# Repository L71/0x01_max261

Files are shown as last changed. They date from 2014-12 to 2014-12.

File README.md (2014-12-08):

0x01_max261
===========

This Maxim Max261 based Eurorack filter module is making this filter IC useful
for audio processing in a standard 16HP Eurorack synth module. 
The IC is a dual filter and each filter is independently controlled using front
panel knobs and control voltage inputs. The filter mode selection buttons provide
these filter types in each filter section:
Low pass, band pass, high pass, notch (lowpass+highpass mixed).
The maximum frequency range is logarithmic 30Hz-16.6KHz with the current firmware.

There are separate knobs and CV inputs for the frequency and resonance of each filter.
The resulting control voltages are read by an Atmel ATmega328 microcontroller that
is programming the max261 filter IC. It also provides the clock signals to
the filter sections. 

The output of filter A is connected to the input of filter B if no cables are inserted.

The filter IC used is not built for use in musical instruments. It suffers from some
clock signal bleed (+- 4mV at 50x the filter cutoff frequency) and due to its switched
capacitor technology it behaves somewhat like a sampled system and has a Nyquist
frequency at 25x the filter cutoff frequency. The clock bleed will be audible in LP
mode with low cutoff values if the filter is the last unit in the signal chain.
Make sure to read the Maxim max261 data sheets if you plan to build one of these. 

The microcontroller source code is released under the GPL v3.0 license. 
The PCBs and front panel drawings are released under the Creative Commons CC BY-SA 4.0 license.

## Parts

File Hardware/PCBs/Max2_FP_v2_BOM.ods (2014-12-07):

Qty | Value | Device | Parts | Description
20 | 100k | R-EU_0207/2V | R1, R2, R3, R4, R6, R9, R11, R12, R13, R14, R15, R16, R19, R20, R21, R22, R23, R24, R25, R26
3 | 100n | C-EU025-025X050 | C7, C8, C9 | Ceramic capacitors
6 | 100n | C-EU050-025X075 | C5, C6, C11, C12, C13, C14 | DC elimination capacitors. Can be skipped if desired.
4 | 100p | C-EU025-025X050 | C1, C2, C3, C4 | Ceramics, 47-100pF OK.
4 | 10k | POT_USVERTICAL | R5_AF, R8_AQ, R17_BF, R18_BQ | ALPS 10K lin PCB mount potentiometer Mouser Pt No 688-RK09D1130C2P
2 | 1k | R-EU_0207/2V | R7, R10
8 | AUDIO-JACKERTHENVAR | AUDIO-JACKERTHENVAR | AU_A_IN, AU_A_OUT, AU_B_IN, AU_B_OUT, CV_AF_IN, CV_AQ_IN, CV_BF_IN, CV_BQ_IN | Switching Mono 3.5mm Audio Jack from Erthenvar.
1 | AUDIO | PINHD-1X10 | JP3 | Arduino board stacking connector (mounted on back side of PCB)
1 | CVs | PINHD-1X8 | JP2 | Arduino board stacking connector (mounted on back side of PCB)
1 | Power | PINHD-1X8 | JP1 | Arduino board stacking connector (mounted on back side of PCB)
6 | TL2285 | TL2285 | A_BP, A_HP, A_LP, B_BP, B_HP, B_LP | E-Switch TL2285 (PCB switch, latching) Mouser Pt.No. 612-TL2285EE300Q
1 | TS924N | TS924N | IC1 | R2R Opamp (Prototypes use TLV2374)
6 | cap for switch SW1 |  |  | Mouser part no 612-1RWHT, 612-1R-BK, 612-1R-RD
4 | knobs for potentiometers |  |  | The pots mentioned have 6mm D-shaped shafts. The panel is designed to have bigger knobs for the frequency settings.
1 | 0x01 Panel IO PCB
1 | 0x01 Front panel
8 | 12mm M3 spacer bolts |  |  | Total 8. Screw → front panel → spacer → PCB → spacer-> PCB → nut.
4 | 6mm M3 screws
4 | M3 nuts

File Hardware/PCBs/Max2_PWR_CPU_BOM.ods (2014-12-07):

Qty | Value | Device | Parts | Description
1 |  | AVR_SPI_PRG_6NS | ISP | AVR ISP 6 Pin header for MCU programming
1 |  | LED3MM | LED1 | LED for MCU life indicator
8 | 100K | R-EU_0207/2V | R1, R3, R7, R8, R11, R12, R15, R16
11 | 100nF | C-EU025-025X050 | C7, C8, C13, C21, C22, C23, C24, C27, C28, C33, C34 | Ceramic capacitors
1 | 10K | R-EU_0207/2V | R17
4 | 10nF | C-EU025-025X050 | C9, C10, C11, C12 | Ceramic capacitors
1 | 1K | R-EU_0207/2V | R2 | LED current limiting resistor. 4,7-10 K OK with very bright LEDs.
2 | 1N4004 | 1N4004 | D1, D2 | 1N4001 also OK.
1 | 20MHz | CRYSTALHC49S | Q1 | 20MHz crystal. Make sure its specs matches C2 and C3.
2 | 22pF | C-EU025-025X050 | C2, C3
4 | 22uF | CPOL-EUE2.5-7 | C1, C4, C5, C6 | Electrolytic capacitors
2 | 4,7uF | CPOL-EUE2.5-6 | C15, C16 | Electrolytic capacitors
1 | 7805 | 78XXS | IC3 | Voltage regulator +5V TO220
1 | 7905 | 79XXS | IC4 | Voltage regulator -5V TO220
1 | ATmega328P | MEGA8-P | IC2 | Atmel ATmega328P DIL28 microcontroller. Also works with (likely) 88s and 168s (tested).
1 | Eurorack power | PINHD-2X5 | JP1 | 2x5 2.54mm pin header for Eurorack power supply.
1 | MAX261 | MAX261 | IC1 | Maxim Max261 filter IC DIL24.
2 | MCP6002 | MCP602P | IC5, IC6 | Single Supply CMOS opamps
3 | pin headers |  |  | 2x8 pin, 1x10pin pin headers for board stacking (mounted on back side of PCB)

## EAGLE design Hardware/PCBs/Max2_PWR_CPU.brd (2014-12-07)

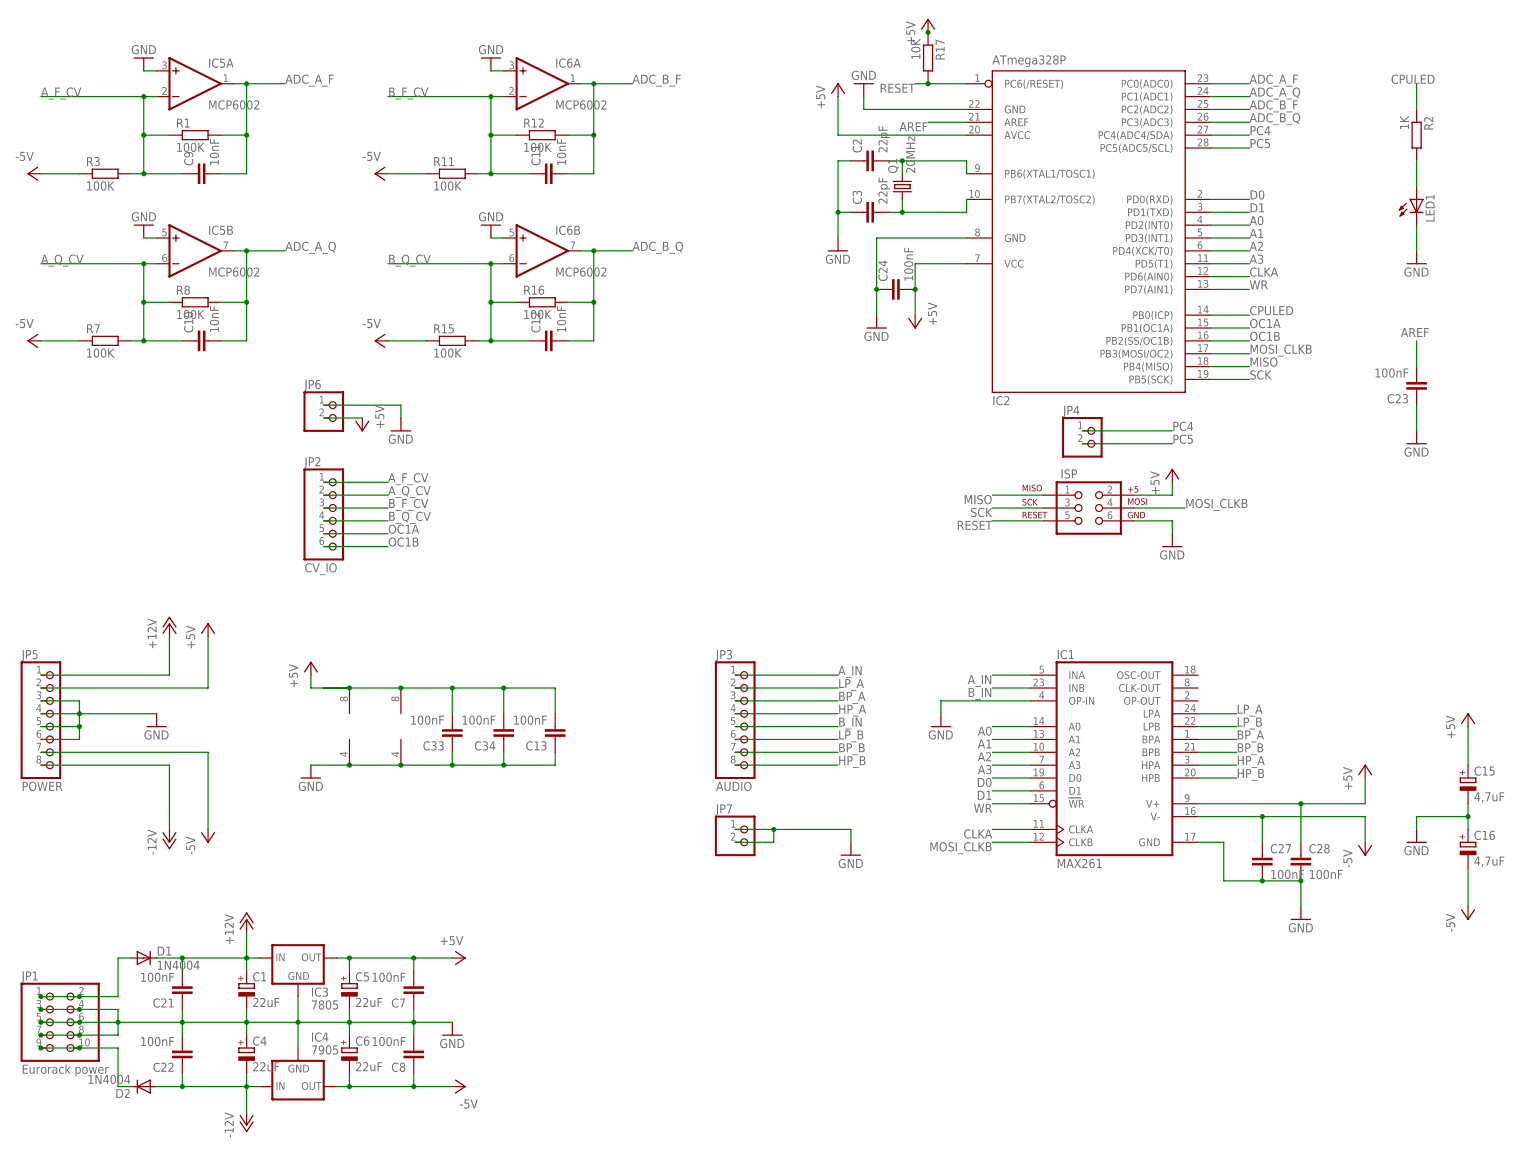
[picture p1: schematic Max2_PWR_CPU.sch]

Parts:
C1, C4, C5, C6: 22uF; E2,5-7
C2, C3: 22pF; C025-025X050
C7, C8, C13, C21, C22, C23, C24, C27, C28, C33, C34: 100nF; C025-025X050
C9, C10, C11, C12: 10nF; C025-025X050
C15, C16: 4,7uF; E2,5-6
D1, D2: 1N4004; DO41-10
IC1: MAX261; DIL24-3
IC2: ATmega328P; DIL28-3
IC3: 7805; 78XXS
IC4: 7905; 79XXS
IC5, IC6: MCP6002; DIL08
ISP: AVR_SPI_PRG_6NS; 2X3-NS
JP1: Eurorack power; 2X05
JP2: CV_IO; 1X06
JP3: AUDIO; 1X08
JP4, JP6, JP7: PINHD-1X2; 1X02
JP5: POWER; 1X08
LED1: LED3MM
Q1: 20MHz; HC49/S
R1, R3, R7, R8, R11, R12, R15, R16: 100K; 0207/2V
R2: 1K; 0207/2V
R17: 10K; 0207/2V

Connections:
+5V: C5.+, C7.2, C13.2, C15.+, C24.2, C28.1, C33.2, C34.2, IC1.9 (V+), IC2.7 (VCC), IC2.20 (AVCC), IC3.OUT, IC5.8 (V+), IC6.8 (V+), ISP.2, JP5.2, JP6.2, R17.1
+12V: C1.+, C21.2, D1.C, IC3.IN, JP5.1
-5V: C6.-, C8.1, C16.-, C27.1, IC1.16 (V-), IC4.OUT, JP5.7, R3.1, R7.1, R11.1, R15.1
-12V: C4.-, C22.1, D2.A, IC4.IN, JP5.8
A0: IC1.14 (A0), IC2.4 (PD2(INT0))
A1: IC1.13 (A1), IC2.5 (PD3(INT1))
A2: IC1.10 (A2), IC2.6 (PD4(XCK/T0))
A3: IC1.7 (A3), IC2.11 (PD5(T1))
ADC_A_F: C9.2, IC2.23 (PC0(ADC0)), IC5.1 (OUT), R1.2
ADC_A_Q: C10.2, IC2.24 (PC1(ADC1)), IC5.7 (OUT), R8.2
ADC_B_F: C11.2, IC2.25 (PC2(ADC2)), IC6.1 (OUT), R12.2
ADC_B_Q: C12.2, IC2.26 (PC3(ADC3)), IC6.7 (OUT), R16.2
AREF: C23.2, IC2.21 (AREF)
A_F_CV: C9.1, IC5.2 (-IN), JP2.1, R1.1, R3.2
A_IN: IC1.5 (INA), JP3.1
A_Q_CV: C10.1, IC5.6 (-IN), JP2.2, R7.2, R8.1
BP_A: IC1.1 (BPA), JP3.3
BP_B: IC1.21 (BPB), JP3.7
B_F_CV: C11.1, IC6.2 (-IN), JP2.3, R11.2, R12.1
B_IN: IC1.23 (INB), JP3.5
B_Q_CV: C12.1, IC6.6 (-IN), JP2.4, R15.2, R16.1
CLKA: IC1.11 (CLKA), IC2.12 (PD6(AIN0))
CPULED: IC2.14 (PB0(ICP)), R2.1
D0: IC1.19 (D0), IC2.2 (PD0(RXD))
D1: IC1.6 (D1), IC2.3 (PD1(TXD))
GND: C1.-, C2.1, C3.1, C4.+, C5.-, C6.+, C7.1, C8.2, C13.1, C15.-, C16.+, C21.1, C22.2, C23.1, C24.1, C27.2, C28.2, C33.1, C34.1, IC1.4 (OP-IN), IC1.17 (GND), IC2.8 (GND), IC2.22 (GND), IC3.GND, IC4.GND, IC5.3 (+IN), IC5.4 (V-), IC5.5 (+IN), IC6.3 (+IN), IC6.4 (V-), IC6.5 (+IN), ISP.6, JP1.3, JP1.4, JP1.5, JP1.6, JP1.7, JP1.8, JP5.3, JP5.4, JP5.5, JP5.6, JP6.1, JP7.1, JP7.2, LED1.K (C)
HP_A: IC1.3 (HPA), JP3.4
HP_B: IC1.20 (HPB), JP3.8
LP_A: IC1.24 (LPA), JP3.2
LP_B: IC1.22 (LPB), JP3.6
MISO: IC2.18 (PB4(MISO)), ISP.1
MOSI_CLKB: IC1.12 (CLKB), IC2.17 (PB3(MOSI/OC2)), ISP.4
unnamed: C2.2, IC2.9 (PB6(XTAL1/TOSC1)), Q1.2
unnamed: C3.2, IC2.10 (PB7(XTAL2/TOSC2)), Q1.1
unnamed: LED1.A, R2.2
unnamed: D1.A, JP1.1, JP1.2
unnamed: D2.C, JP1.9, JP1.10
OC1A: IC2.15 (PB1(OC1A)), JP2.5
OC1B: IC2.16 (PB2(SS/OC1B)), JP2.6
PC4: IC2.27 (PC4(ADC4/SDA)), JP4.1
PC5: IC2.28 (PC5(ADC5/SCL)), JP4.2
RESET: IC2.1 (PC6(/RESET)), ISP.5, R17.2
SCK: IC2.19 (PB5(SCK)), ISP.3
WR: IC1.15 (WR), IC2.13 (PD7(AIN1))

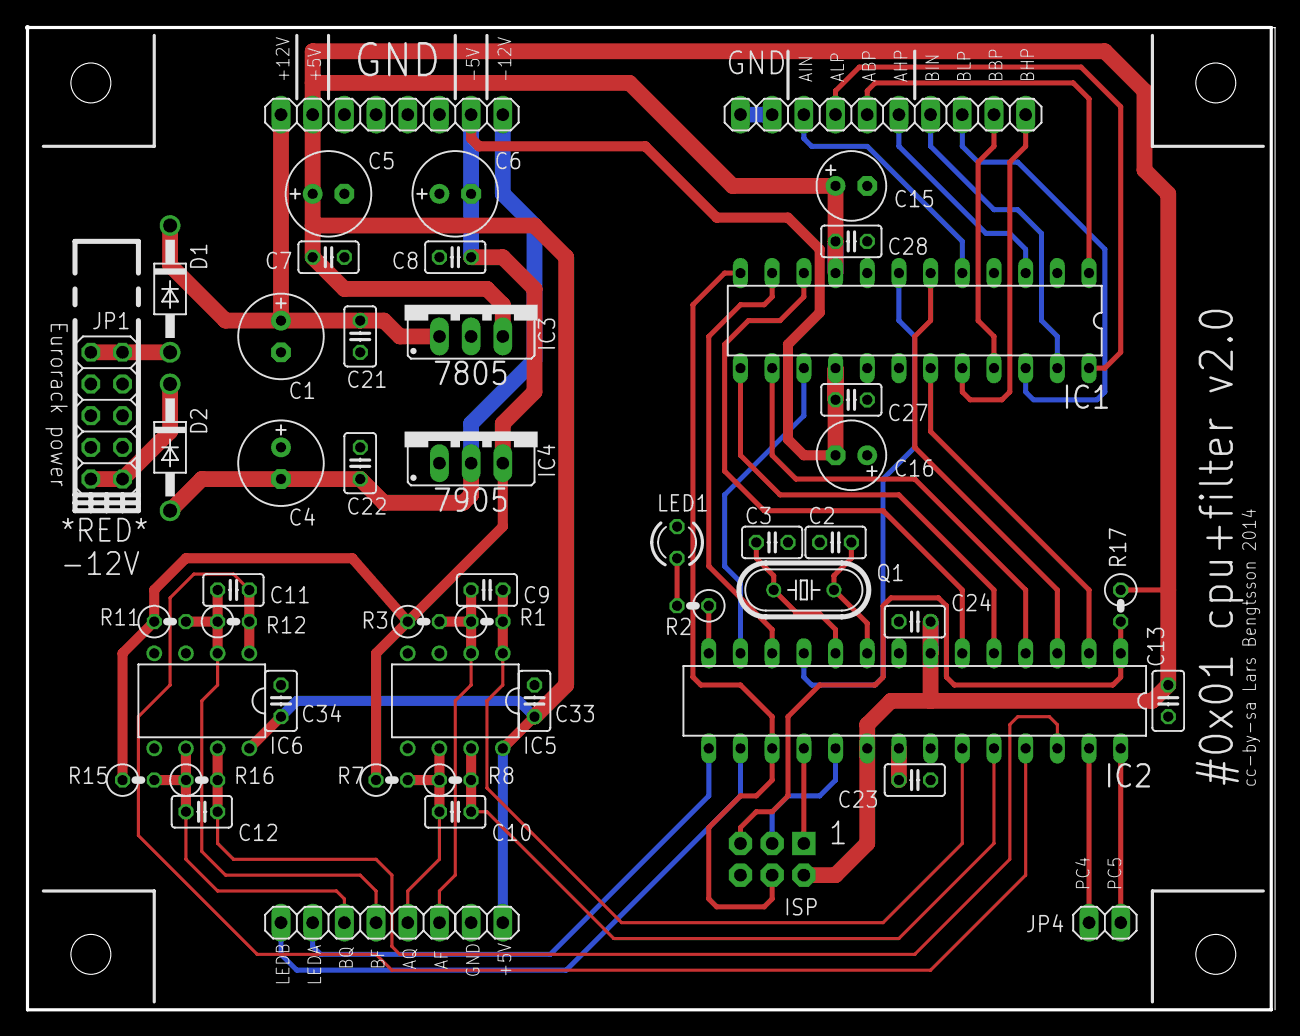
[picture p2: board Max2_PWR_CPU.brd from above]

Board: 2 copper layers, 99.7 x 78.7 mm, 51 parts (0 on the bottom side), 44 nets.

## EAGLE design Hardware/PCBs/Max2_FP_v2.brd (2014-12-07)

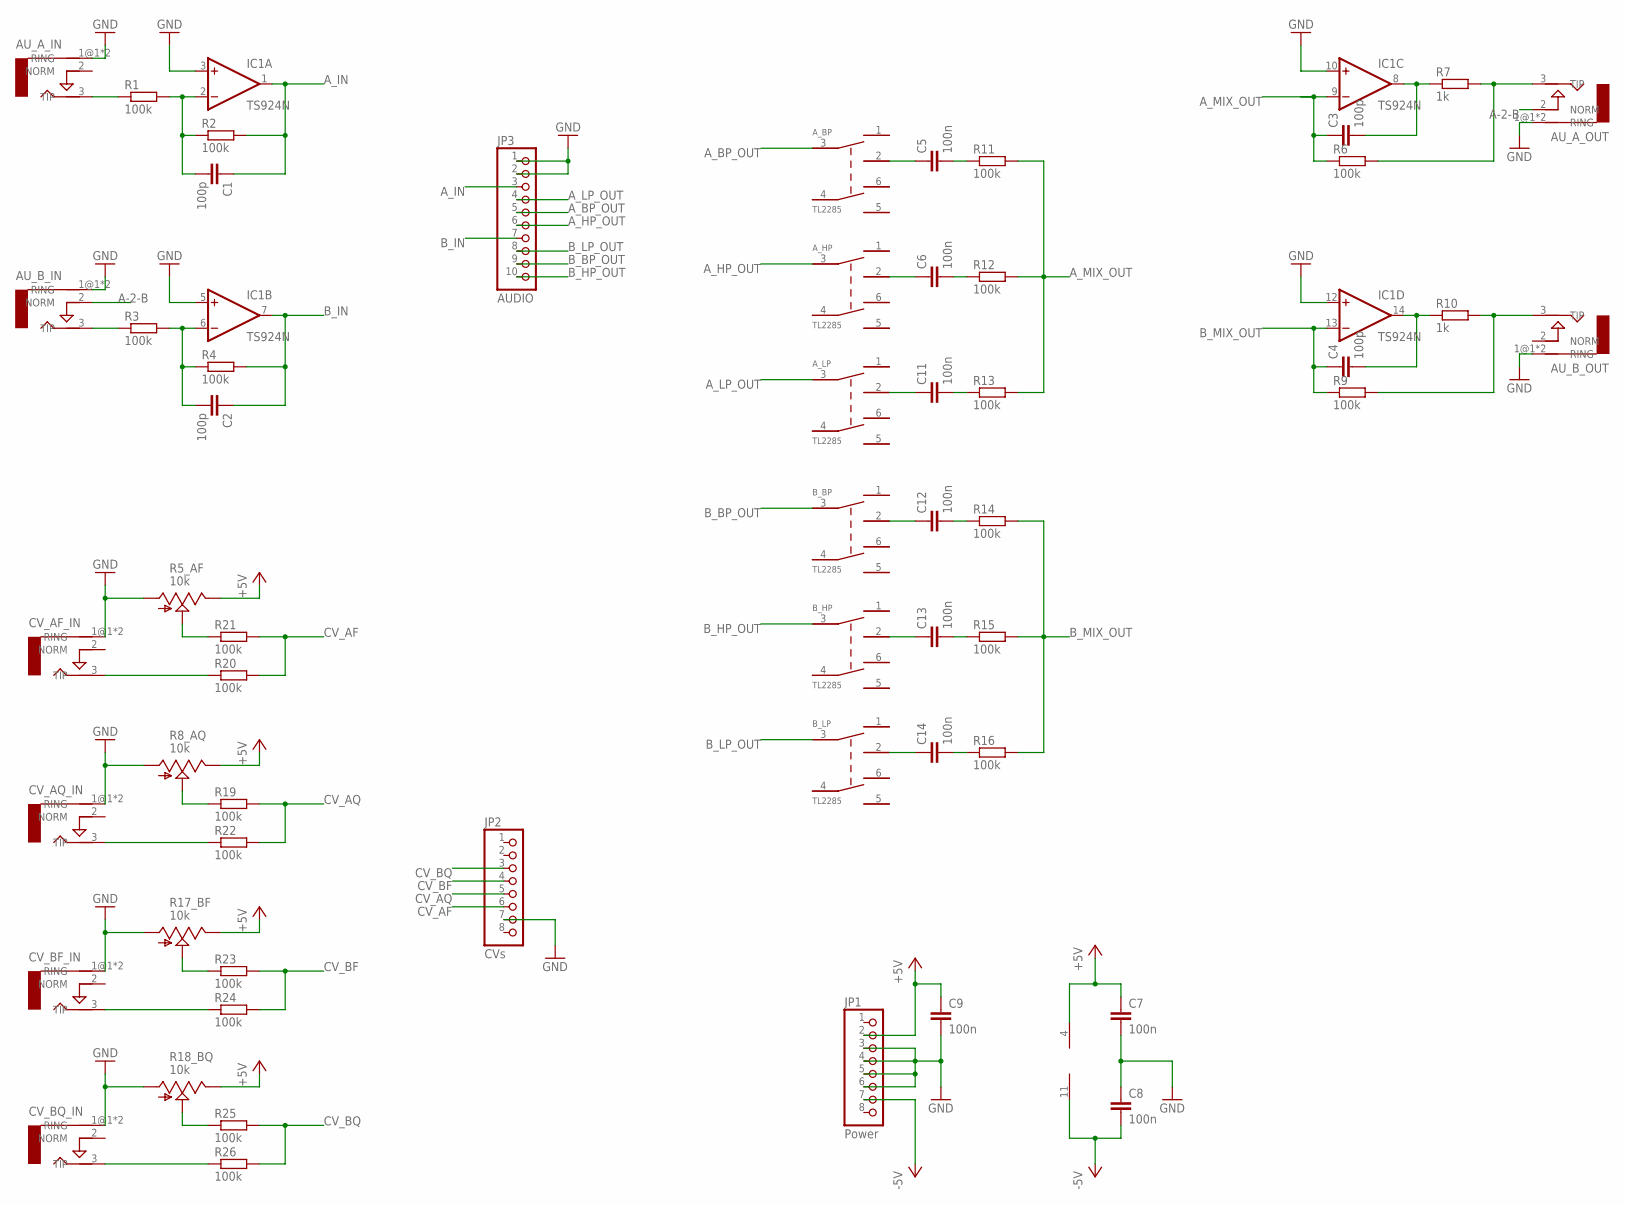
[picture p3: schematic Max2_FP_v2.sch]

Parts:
AU_A_IN: AUDIO-JACKERTHENVAR; ERTHENVAR-JACK
AU_A_OUT: AUDIO-JACKERTHENVAR; ERTHENVAR-JACK
AU_B_IN: AUDIO-JACKERTHENVAR; ERTHENVAR-JACK
AU_B_OUT: AUDIO-JACKERTHENVAR; ERTHENVAR-JACK
A_BP: TL2285; TL2285_PCB
A_HP: TL2285; TL2285_PCB
A_LP: TL2285; TL2285_PCB
B_BP: TL2285; TL2285_PCB
B_HP: TL2285; TL2285_PCB
B_LP: TL2285; TL2285_PCB
C1, C2, C3, C4: 100p; C025-025X050
C5, C6, C11, C12, C13, C14: 100n; C050-025X075
C7, C8, C9: 100n; C025-025X050
CV_AF_IN: AUDIO-JACKERTHENVAR; ERTHENVAR-JACK
CV_AQ_IN: AUDIO-JACKERTHENVAR; ERTHENVAR-JACK
CV_BF_IN: AUDIO-JACKERTHENVAR; ERTHENVAR-JACK
CV_BQ_IN: AUDIO-JACKERTHENVAR; ERTHENVAR-JACK
IC1: TS924N; DIL14
JP1: Power; 1X08
JP2: CVs; 1X08
JP3: AUDIO; 1X10
R1, R2, R3, R4, R6, R9, R11, R12, R13, R14, R15, R16, R19, R20, R21, R22, R23, R24, R25, R26: 100k; 0207/2V
R5_AF, R8_AQ, R17_BF, R18_BQ: 10k; ALPS_POT_VERTICAL
R7, R10: 1k; 0207/2V

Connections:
+5V: C7.1, C9.1, IC1.4 (V+), JP1.2, R5_AF.P$1 (E), R8_AQ.P$1 (E), R17_BF.P$1 (E), R18_BQ.P$1 (E)
-5V: C8.2, IC1.11 (V-), JP1.7
A-2-B: AU_A_OUT.2 (NORM), AU_B_IN.2 (NORM)
A_BP_OUT: A_BP.3, JP3.5
A_HP_OUT: A_HP.3, JP3.6
A_IN: C1.1, IC1.1 (OUT), JP3.3, R2.2
A_LP_OUT: A_LP.3, JP3.4
A_MIX_OUT: C3.1, IC1.9 (-IN), R6.1, R11.2, R12.2, R13.2
B_BP_OUT: B_BP.3, JP3.9
B_HP_OUT: B_HP.3, JP3.10
B_IN: C2.1, IC1.7 (OUT), JP3.7, R4.2
B_LP_OUT: B_LP.3, JP3.8
B_MIX_OUT: C4.1, IC1.13 (-IN), R9.1, R14.2, R15.2, R16.2
CV_AF: JP2.6, R20.2, R21.2
CV_AQ: JP2.5, R19.2, R22.2
CV_BF: JP2.4, R23.2, R24.2
CV_BQ: JP2.3, R25.2, R26.2
GND: AU_A_IN.1@1 (RING), AU_A_IN.1@2 (RING), AU_A_OUT.1@1 (RING), AU_A_OUT.1@2 (RING), AU_B_IN.1@1 (RING), AU_B_IN.1@2 (RING), AU_B_OUT.1@1 (RING), AU_B_OUT.1@2 (RING), C7.2, C8.1, C9.2, CV_AF_IN.1@1 (RING), CV_AF_IN.1@2 (RING), CV_AQ_IN.1@1 (RING), CV_AQ_IN.1@2 (RING), CV_BF_IN.1@1 (RING), CV_BF_IN.1@2 (RING), CV_BQ_IN.1@1 (RING), CV_BQ_IN.1@2 (RING), IC1.3 (+IN), IC1.5 (+IN), IC1.10 (+IN), IC1.12 (+IN), JP1.3, JP1.4, JP1.5, JP1.6, JP2.7, JP3.1, JP3.2, R5_AF.P$3 (A), R8_AQ.P$3 (A), R17_BF.P$3 (A), R18_BQ.P$3 (A)
unnamed: A_BP.2, C5.1
unnamed: AU_A_IN.3 (TIP), R1.1
unnamed: C1.2, IC1.2 (-IN), R1.2, R2.1
unnamed: C3.2, IC1.8 (OUT), R7.1
unnamed: AU_A_OUT.3 (TIP), R6.2, R7.2
unnamed: C5.2, R11.1
unnamed: C2.2, IC1.6 (-IN), R3.2, R4.1
unnamed: AU_B_IN.3 (TIP), R3.1
unnamed: C6.2, R12.1
unnamed: A_HP.2, C6.1
unnamed: A_LP.2, C11.1
unnamed: C11.2, R13.1
unnamed: C4.2, IC1.14 (OUT), R10.1
unnamed: AU_B_OUT.3 (TIP), R9.2, R10.2
unnamed: B_BP.2, C12.1
unnamed: R5_AF.P$2 (S), R21.1
unnamed: C12.2, R14.1
unnamed: CV_AF_IN.3 (TIP), R20.1
unnamed: CV_BQ_IN.3 (TIP), R26.1
unnamed: B_HP.2, C13.1
unnamed: CV_AQ_IN.3 (TIP), R22.1
unnamed: R8_AQ.P$2 (S), R19.1
unnamed: R17_BF.P$2 (S), R23.1
unnamed: C13.2, R15.1
unnamed: CV_BF_IN.3 (TIP), R24.1
unnamed: R18_BQ.P$2 (S), R25.1
unnamed: B_LP.2, C14.1
unnamed: C14.2, R16.1

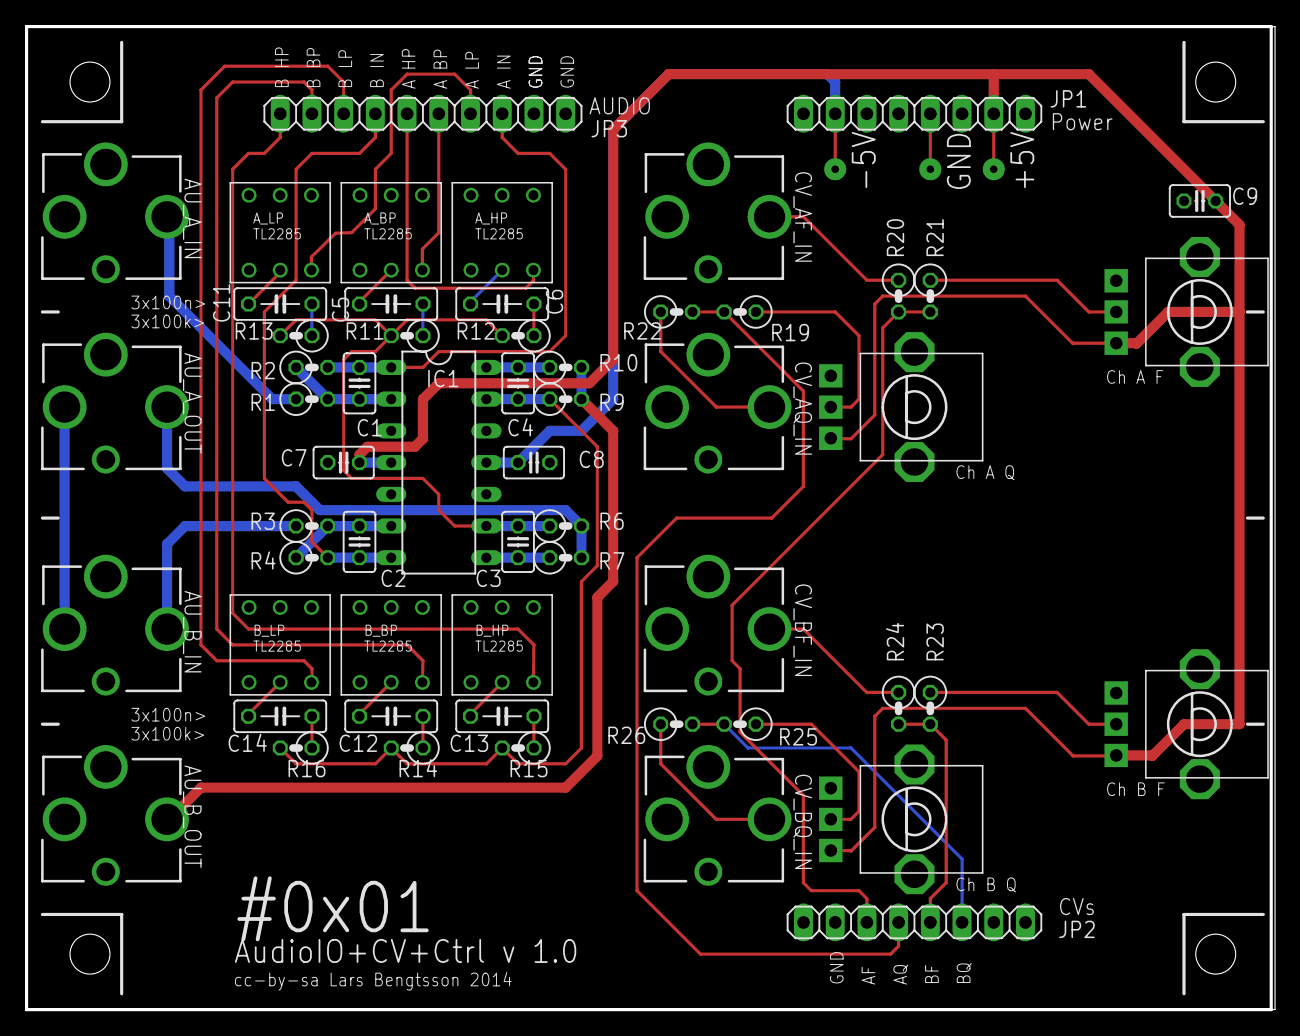
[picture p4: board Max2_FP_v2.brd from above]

Board: 2 copper layers, 100.0 x 78.7 mm, 57 parts (0 on the bottom side), 46 nets.

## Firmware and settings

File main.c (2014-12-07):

#define F_CPU 20000000UL

#include <avr/io.h>
#include <util/delay.h>
#include <avr/interrupt.h>

#include "adc.h"
#include "filterclock.h"
#include "max261.h"


void setup_leftover_pins() {
	// enable pull-up resistors on PC4 and PC5
	PORTC |= 0x30;
	
	// same on PB1,PB2 (OC1A, OC1B, LED status pins originally)
	PORTB |= 0x06;
}


int main() {

    // PB0 = output for I'm Alive Blink
    DDRB |= (1<<PB0);

	// blink PB0 LED once.
	PORTB |= 0b00000001;
	_delay_ms(200);
	PORTB &= 0b11111110;
	_delay_ms(200);
	PORTB |= 0b00000001;

	// setup & run system timer
	// setup_system_timer(); // DISABLED.
	
	// start frequency generator timers
	setup_f_timer();

	// initialize filter hw
	init_max261();
	
	// set filter modes (See max261 data sheet for details)
	// 1:  LP, BP, N
	// 2:  LP, BP, N (other characteristics)
	// 3:  LP, BP, HP
	// 4:  LP, BP, AP
	set_mode(2, 0);	// Filter A mode 3
	set_mode(2, 1);	// Filter B mode 3
	max261_write_f(1, 0);	// preset filter A F
	max261_write_f(1, 1);	// preset filter B F
	
	// do something with leftover IO pins
	setup_leftover_pins();
	
	// launch ADC conversions
	setup_adc();
	run_adc_timer();

    // Enable interrupts for all. GO! =)
    SREG |= 0x80 ;
	
    // main loop
    while ( 1 )  {
		PORTB |= 0b00000001;
        _delay_ms(2000);
		PORTB &= 0b11111110;
		_delay_ms(2000);
    }
  
}

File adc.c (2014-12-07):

// ADC handling

#include <avr/io.h>
#include <avr/interrupt.h>
#include <avr/pgmspace.h>
#include "max261.h"
#include "lookuptable.h"

// setup interrupt timer
void run_adc_timer() {
	
	OCR1AH = 0x13;	// 20000000/5000 -> 4KHz timer
	OCR1AL = 0x88;  // this means every CV / Pot will be read & updated at 1 KHz.
	
	// clear on OCR1A hit, prescaler=1.
	TCCR1B |= (1<<WGM12) | (1<<CS10) ;
	
	// enable OCR1A interrupt
	TIMSK1 |= (1<<OCIE1A);
	
}


// setup ADC & trigger first conversion
void setup_adc() {

	// enable ADC, prescaler = /64 -> 312.5 KHz ADC clock. 
	ADCSRA |= (1<<ADEN) | (1<<ADPS2) | (1<<ADPS1) ; 
	
	// disable digital IOs on used ADC pins
	DIDR0 = 0x0f ;
	
	// v.ref = AREF, left adjust, channel selected=0.
	ADMUX |= (1<<ADLAR) | (1<<REFS0) ;
	
	// go conversions!
	ADCSRA |= (1<<ADSC) ;

}

// ADC interrupt handler & next-conversion-trigger
ISR(TIMER1_COMPA_vect) {

	// ISR indicator
	// PORTB |= 0b00000001;
	
	static uint8_t adc_chan = 0 ;		// currently selected ADC channel
	static uint8_t adc_last_value[4];
	uint8_t adc_mask = 0b00000011 ; 	// mask of bits used for ADC channel selection
	
	// read ADC register(s)
	uint8_t adc_in = ADCH ;
	uint8_t adc_in_neg = 255-adc_in ;
	
	if ( adc_in != adc_last_value[adc_chan] ) {	// only update if input has changed
		// PORTB |= 0b00000001; 
		switch (adc_chan) {
			case 0 :	// filter A F
				max261_write_f(adc_in >> 2, 0);
				OCR0A = pgm_read_byte(&divider[adc_in_neg]);
				TCCR0B = pgm_read_byte(&prescaler[adc_in_neg]);
				break ;
			
			case 1 :	// filter A Q
				max261_write_q((adc_in_neg >> 1), 0);
				break ;
			
			case 2 :	// filter B F
				max261_write_f(adc_in >> 2, 1);
				OCR2A = pgm_read_byte(&divider[adc_in_neg]);
				TCCR2B = pgm_read_byte(&prescaler[adc_in_neg]);
				break ;
			
			case 3 :	// filter B Q
				max261_write_q((adc_in_neg >> 1), 1);
				break;
		}
	} 
	
	// save adc value for next time...
	adc_last_value[adc_chan] = adc_in;
	
	// channel number +1
	adc_chan = ((adc_chan+1) & adc_mask ) ;
	
	// update ADMUX register
	ADMUX &= 0xf0;	// reset channel bits
	ADMUX |= adc_chan ;
	
	// start next conversion
	ADCSRA |= (1<<ADSC) ;
	
	// turn off ISR indicator
	// PORTB &= 0b11111110;
}

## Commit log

2014-12-07 Added PCB files.
    [Max2_FP_v2.brd, Max2_FP_v2.sch, Max2_PWR_CPU.brd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]
2014-12-07 Added BOM files.
    [Max2_FP_v2_BOM.ods, Max2_PWR_CPU_BOM.ods]
2014-12-08 Fixed error in filter mode description.

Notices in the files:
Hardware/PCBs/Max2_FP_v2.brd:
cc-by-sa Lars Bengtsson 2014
